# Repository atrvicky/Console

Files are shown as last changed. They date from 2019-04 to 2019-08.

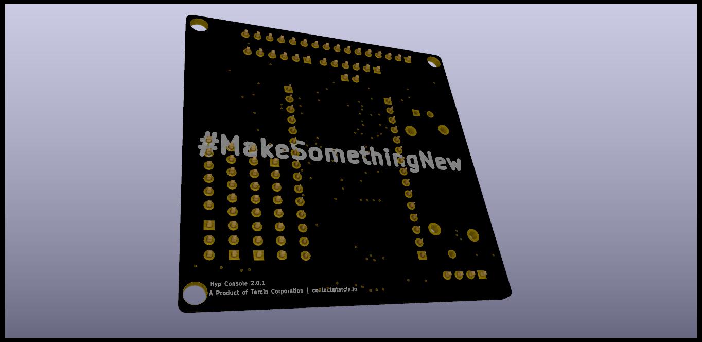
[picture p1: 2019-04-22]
renders/rear.jpg

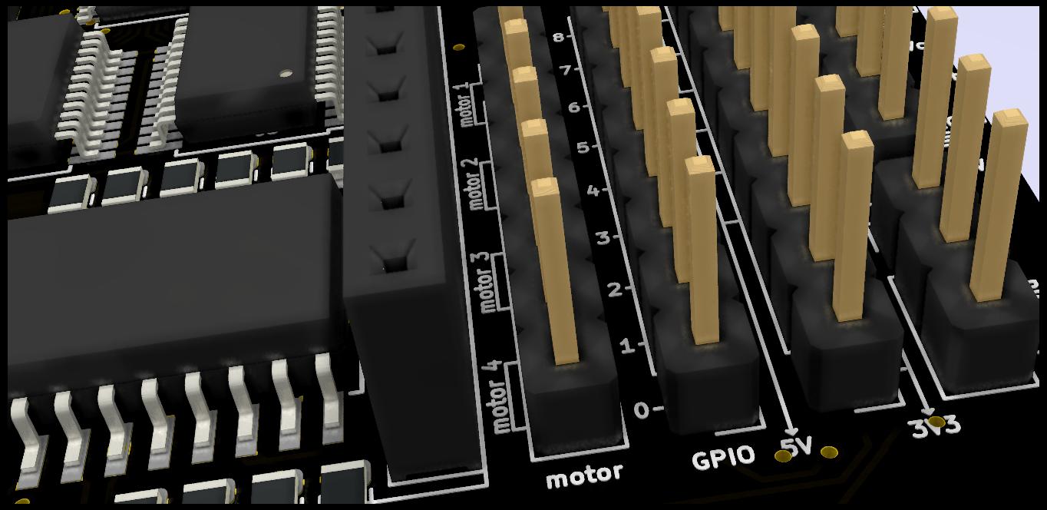
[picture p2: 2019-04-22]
renders/motor_gpio.jpg

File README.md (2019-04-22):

# Console
PCB design of the Hyp Console - an esp8266 powered board, powered by microPython and a ton of embedded functionalities out of the box.

The console has the following features:

* I2C Expander.
* Native LCD support.
* Native support for upto 3 external LEDs (PWM enabled).
* One default LED (PWM enabled).
* Native support for upto 4 DC motors, 2 Steppers, one ultrasound sensor and two infrared sensors.
* Integrated accelerometer with freefall detection, tap detection, doub click detection.
* Dedicated PWM controller and I2C port expander.
* MOSFET controllers for motors for enhanced current delivery to the motors.
* 9 GPIO pins.
* Stabilised 3V3 and 5V outputs.

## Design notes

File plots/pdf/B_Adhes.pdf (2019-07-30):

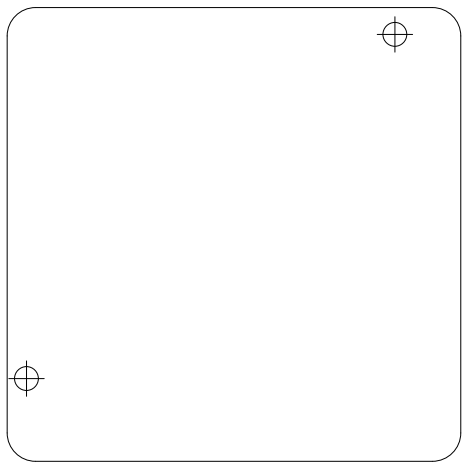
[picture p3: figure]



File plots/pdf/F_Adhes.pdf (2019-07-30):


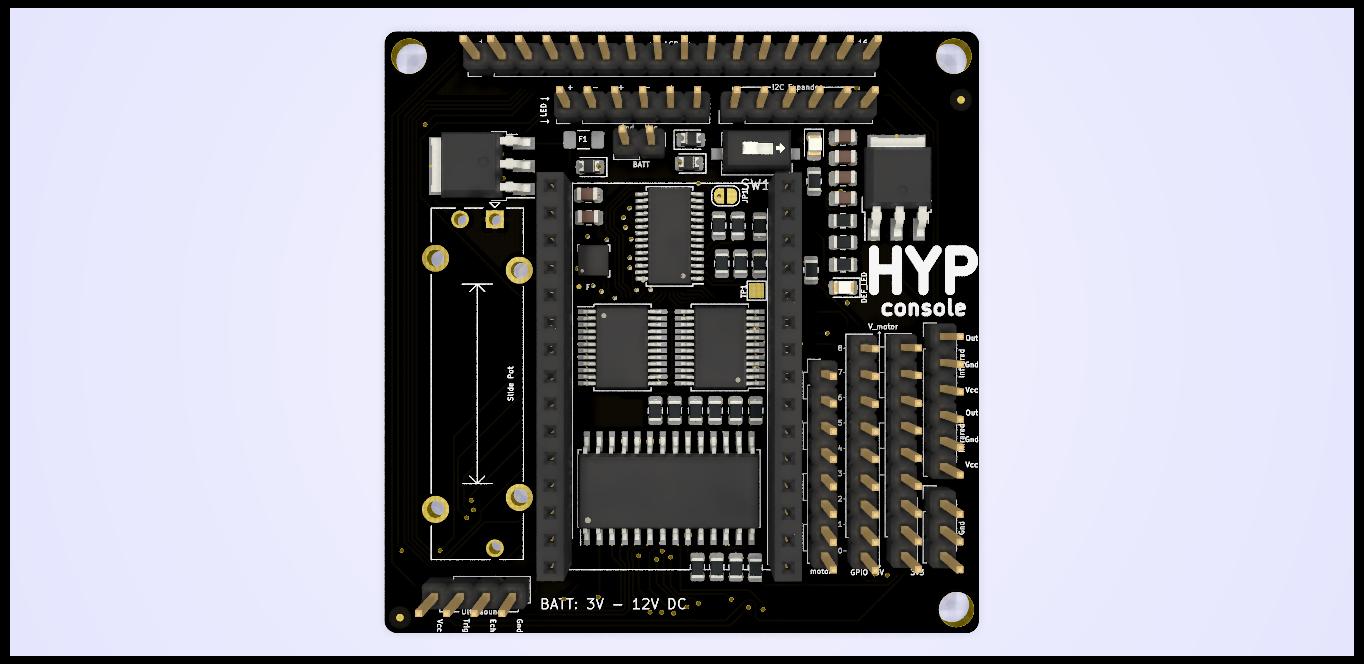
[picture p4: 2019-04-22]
renders/top.jpg

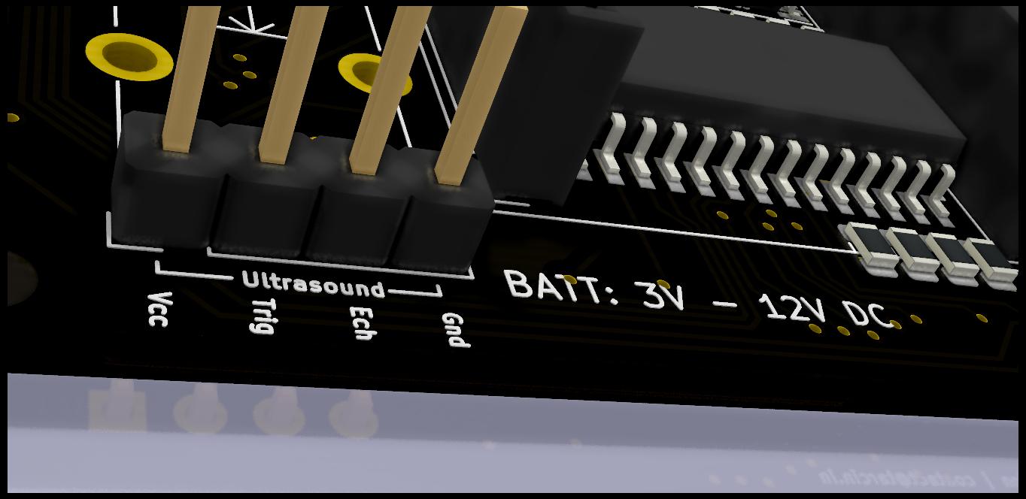
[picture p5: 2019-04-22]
renders/US.jpg

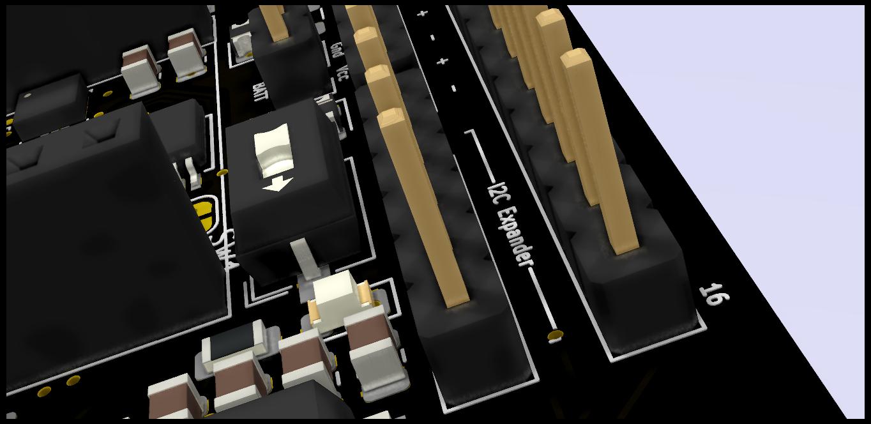
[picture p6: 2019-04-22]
renders/i2c.jpg

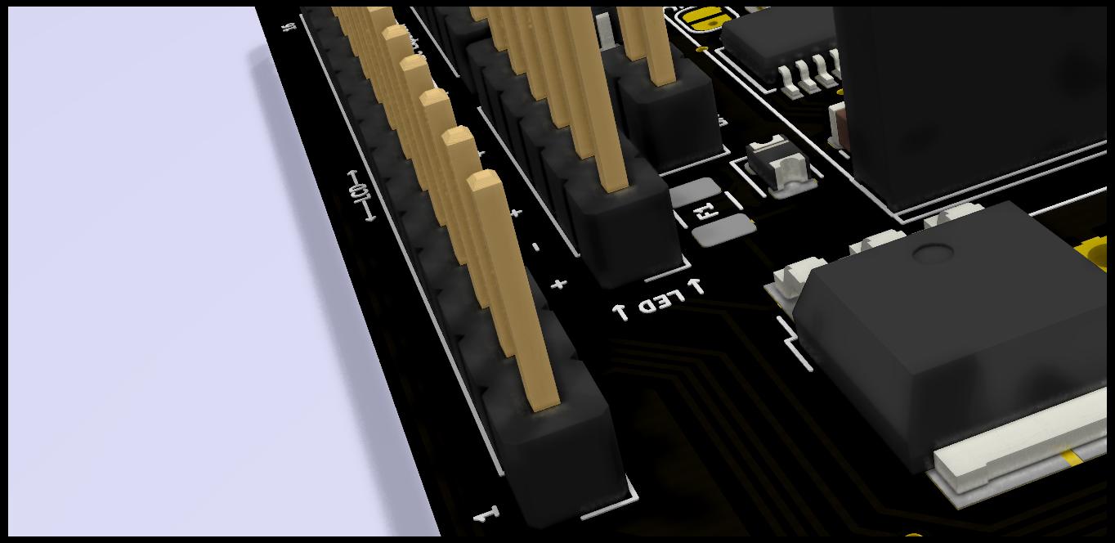
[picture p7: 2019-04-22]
renders/lcd_led.jpg

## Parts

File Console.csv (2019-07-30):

Source: | G:\Studio\Hardware\kiCad\Console\Console.sch
Date: | 07/30/19 22:16:01
Tool: | Eeschema (5.1.0)-1
Generator: | G:\Program Files\KiCad\bin\scripting\plugins/bom_csv_grouped_by_value.py
Component Count: | 56
Individual Components:
Item | Qty | Reference(s) | Value | LibPart | Footprint | Datasheet
 |  | C1 | 10uF | Device:C | Capacitor_SMD:C_0805_2012Metric | ~
 |  | C2 | 1uF | Device:C | Capacitor_SMD:C_0805_2012Metric | ~
 |  | C3 | 1uF | Device:C | Capacitor_SMD:C_0805_2012Metric | ~
 |  | C4 | 1uF | Device:C | Capacitor_SMD:C_0805_2012Metric | ~
 |  | C5 | 10uF | Device:C | Capacitor_SMD:C_0805_2012Metric | ~
 |  | C6 | 1uF | Device:C | Capacitor_SMD:C_0805_2012Metric | ~
 |  | D1 | LED | Device:LED | LED_SMD:LED_0805_2012Metric | ~
 |  | D2 | LED | Device:LED | LED_SMD:LED_0805_2012Metric | ~
 |  | D3 | MBR120 | Device:D | Diode_SMD:D_0805_2012Metric | ~
 |  | D4 | MBR120 | Device:D | Diode_SMD:D_0805_2012Metric | ~
 |  | D5 | MBR120 | Device:D | Diode_SMD:D_0805_2012Metric | ~
 |  | F1 | Fuse | Device:Fuse | Fuse:Fuse_1206_3216Metric | ~
 |  | J1 | batt_in | Connector:Conn_01x02_Male | Connector_PinHeader_2.54mm:PinHeader_1x02_P2.54mm_Vertical | ~
 |  | J2 | 3v3_gnd | Connector:Conn_01x09_Male | Connector_PinHeader_2.54mm:PinHeader_1x09_P2.54mm_Vertical | ~
 |  | J3 | motor_out | Connector:Conn_01x08_Male | Connector_PinHeader_2.54mm:PinHeader_1x08_P2.54mm_Vertical | ~
 |  | J4 | ir_out | Connector:Conn_01x06_Male | Connector_PinHeader_2.54mm:PinHeader_1x06_P2.54mm_Vertical | ~
 |  | J5 | pwr_jumper | Connector:Conn_01x02_Male | Connector_PinHeader_2.54mm:PinHeader_1x02_P2.54mm_Vertical | ~
 |  | J6 | gpio | Connector:Conn_01x09_Male | Connector_PinHeader_2.54mm:PinHeader_1x09_P2.54mm_Vertical | ~
 |  | J7 | led_out | Connector:Conn_01x06_Male | Connector_PinHeader_2.54mm:PinHeader_1x06_P2.54mm_Vertical | ~
 |  | J8 | sensor_in | Connector:Conn_01x04_Male | Connector_PinHeader_2.54mm:PinHeader_1x04_P2.54mm_Vertical | ~
 |  | J9 | i2c_out | Connector:Conn_01x06_Male | Connector_PinHeader_2.54mm:PinHeader_1x06_P2.54mm_Vertical | ~
 |  | J11 | lcd_out | Connector:Conn_01x16_Male | Connector_PinHeader_2.54mm:PinHeader_1x16_P2.54mm_Vertical | ~
 |  | J14 | gnd_out | Connector:Conn_01x03_Male | Connector_PinHeader_2.54mm:PinHeader_1x03_P2.54mm_Vertical | ~
 |  | J17 | node_conn_1 | Connector:Conn_01x15_Female | Connector_PinSocket_2.54mm:PinSocket_1x15_P2.54mm_Vertical | ~
 |  | J18 | node_conn_2 | Connector:Conn_01x15_Female | Connector_PinSocket_2.54mm:PinSocket_1x15_P2.54mm_Vertical | ~
 |  | JP1 | SolderJumper_2_Open | Jumper:SolderJumper_2_Open | Jumper:SolderJumper-2_P1.3mm_Open_RoundedPad1.0x1.5mm | ~
 |  | NMCU1 | nodeMCU | MCU_Espressif:nodeMCU | Custom:NodeMCU
 |  | R1 | 220 | Device:R | Resistor_SMD:R_0805_2012Metric | ~
 |  | R2 | 220 | Device:R | Resistor_SMD:R_0805_2012Metric | ~
 |  | R3 | 10k | Device:R | Resistor_SMD:R_0805_2012Metric | ~
 |  | R4 | 10k | Device:R | Resistor_SMD:R_0805_2012Metric | ~
 |  | R5 | 10k | Device:R | Resistor_SMD:R_0805_2012Metric | ~
 |  | R6 | 10k | Device:R | Resistor_SMD:R_0805_2012Metric | ~
 |  | R7 | 10k | Device:R | Resistor_SMD:R_0805_2012Metric | ~
 |  | R8 | 10k | Device:R | Resistor_SMD:R_0805_2012Metric | ~
 |  | R9 | 10k | Device:R | Resistor_SMD:R_0805_2012Metric | ~
 |  | R10 | 10k | Device:R | Resistor_SMD:R_0805_2012Metric | ~
 |  | R11 | 10k | Device:R | Resistor_SMD:R_0805_2012Metric | ~
 |  | R12 | 10k | Device:R | Resistor_SMD:R_0805_2012Metric | ~
 |  | R13 | 10k | Device:R | Resistor_SMD:R_0805_2012Metric | ~
 |  | R14 | 10k | Device:R | Resistor_SMD:R_0805_2012Metric | ~
 |  | R15 | 10k | Device:R | Resistor_SMD:R_0805_2012Metric | ~
 |  | R16 | 10k | Device:R | Resistor_SMD:R_0805_2012Metric | ~
 |  | R17 | 10k | Device:R | Resistor_SMD:R_0805_2012Metric | ~
 |  | R18 | 10k | Device:R | Resistor_SMD:R_0805_2012Metric | ~
 |  | R19 | 10k | Device:R | Resistor_SMD:R_0805_2012Metric | ~
 |  | R20 | 220 | Device:R | Resistor_SMD:R_0805_2012Metric | ~
 |  | RV1 | R_POT_TRIM | Device:R_POT_TRIM | Potentiometer_THT:Potentiometer_Bourns_PTA2043_Single_Slide | ~
 |  | SW1 | SW_SPDT | Switch:SW_SPDT | Button_Switch_THT:SW_CuK_OS102011MA1QN1_SPDT_Angled | ~
 |  | U1 | AZ1117-3.3 | Regulator_Linear:AZ1117-3.3 | Package_TO_SOT_SMD:TO-252-3_TabPin2 | https://www.diodes.com/assets/Datasheets/AZ1117.pdf
 |  | U2 | LIS3DH | Sensor_Motion:LIS3DH | Package_LGA:LGA-16_3x3mm_P0.5mm_LayoutBorder3x5y | https://www.st.com/resource/en/datasheet/cd00274221.pdf
 |  | U3 | TB6612FNG | Driver_Motor:TB6612FNG | Package_SO:SSOP-24_5.3x8.2mm_P0.65mm | https://toshiba.semicon-storage.com/us/product/linear/motordriver/detail.TB6612FNG.html
 |  | U4 | PCA9685PW | Driver_LED:PCA9685PW | Package_SO:TSSOP-28_4.4x9.7mm_P0.65mm | http://www.nxp.com/documents/data_sheet/PCA9685.pdf
 |  | U5 | TB6612FNG | Driver_Motor:TB6612FNG | Package_SO:SSOP-24_5.3x8.2mm_P0.65mm | https://toshiba.semicon-storage.com/us/product/linear/motordriver/detail.TB6612FNG.html
 |  | U6 | MCP23017_SP | Interface_Expansion:MCP23017_SP | Package_SO:SOIC-28W_7.5x17.9mm_P1.27mm | http://ww1.microchip.com/downloads/en/DeviceDoc/20001952C.pdf
 |  | U7 | AZ1117-5.0 | Regulator_Linear:AZ1117-5.0 | Package_TO_SOT_SMD:TO-252-3_TabPin2 | https://www.diodes.com/assets/Datasheets/AZ1117.pdf
Collated Components:
Item | Qty | Reference(s) | Value | LibPart | Footprint | Datasheet
1 | 2 | C1, C5 | 10uF | Device:C | Capacitor_SMD:C_0805_2012Metric | ~
2 | 4 | C2, C3, C4, C6 | 1uF | Device:C | Capacitor_SMD:C_0805_2012Metric | ~
3 | 2 | D1, D2 | LED | Device:LED | LED_SMD:LED_0805_2012Metric | ~
4 | 3 | D3, D4, D5 | MBR120 | Device:D | Diode_SMD:D_0805_2012Metric | ~
5 | 1 | F1 | Fuse | Device:Fuse | Fuse:Fuse_1206_3216Metric | ~
6 | 1 | J1 | batt_in | Connector:Conn_01x02_Male | Connector_PinHeader_2.54mm:PinHeader_1x02_P2.54mm_Vertical | ~
7 | 1 | J2 | 3v3_gnd | Connector:Conn_01x09_Male | Connector_PinHeader_2.54mm:PinHeader_1x09_P2.54mm_Vertical | ~
8 | 1 | J3 | motor_out | Connector:Conn_01x08_Male | Connector_PinHeader_2.54mm:PinHeader_1x08_P2.54mm_Vertical | ~
9 | 1 | J4 | ir_out | Connector:Conn_01x06_Male | Connector_PinHeader_2.54mm:PinHeader_1x06_P2.54mm_Vertical | ~
10 | 1 | J5 | pwr_jumper | Connector:Conn_01x02_Male | Connector_PinHeader_2.54mm:PinHeader_1x02_P2.54mm_Vertical | ~
11 | 1 | J6 | gpio | Connector:Conn_01x09_Male | Connector_PinHeader_2.54mm:PinHeader_1x09_P2.54mm_Vertical | ~
12 | 1 | J7 | led_out | Connector:Conn_01x06_Male | Connector_PinHeader_2.54mm:PinHeader_1x06_P2.54mm_Vertical | ~
13 | 1 | J8 | sensor_in | Connector:Conn_01x04_Male | Connector_PinHeader_2.54mm:PinHeader_1x04_P2.54mm_Vertical | ~
14 | 1 | J9 | i2c_out | Connector:Conn_01x06_Male | Connector_PinHeader_2.54mm:PinHeader_1x06_P2.54mm_Vertical | ~
15 | 1 | J11 | lcd_out | Connector:Conn_01x16_Male | Connector_PinHeader_2.54mm:PinHeader_1x16_P2.54mm_Vertical | ~
16 | 1 | J14 | gnd_out | Connector:Conn_01x03_Male | Connector_PinHeader_2.54mm:PinHeader_1x03_P2.54mm_Vertical | ~
17 | 1 | J17 | node_conn_1 | Connector:Conn_01x15_Female | Connector_PinSocket_2.54mm:PinSocket_1x15_P2.54mm_Vertical | ~
18 | 1 | J18 | node_conn_2 | Connector:Conn_01x15_Female | Connector_PinSocket_2.54mm:PinSocket_1x15_P2.54mm_Vertical | ~
19 | 1 | JP1 | SolderJumper_2_Open | Jumper:SolderJumper_2_Open | Jumper:SolderJumper-2_P1.3mm_Open_RoundedPad1.0x1.5mm | ~
20 | 1 | NMCU1 | nodeMCU | MCU_Espressif:nodeMCU | Custom:NodeMCU
21 | 3 | R1, R2, R20 | 220 | Device:R | Resistor_SMD:R_0805_2012Metric | ~
22 | 17 | R3, R4, R5, R6, R7, R8, R9, R10, R11, R12, R13, R14, R15, R16, R17, R18, R19 | 10k | Device:R | Resistor_SMD:R_0805_2012Metric | ~
23 | 1 | RV1 | R_POT_TRIM | Device:R_POT_TRIM | Potentiometer_THT:Potentiometer_Bourns_PTA2043_Single_Slide | ~
24 | 1 | SW1 | SW_SPDT | Switch:SW_SPDT | Button_Switch_THT:SW_CuK_OS102011MA1QN1_SPDT_Angled | ~
25 | 1 | U1 | AZ1117-3.3 | Regulator_Linear:AZ1117-3.3 | Package_TO_SOT_SMD:TO-252-3_TabPin2 | https://www.diodes.com/assets/Datasheets/AZ1117.pdf
26 | 1 | U2 | LIS3DH | Sensor_Motion:LIS3DH | Package_LGA:LGA-16_3x3mm_P0.5mm_LayoutBorder3x5y | https://www.st.com/resource/en/datasheet/cd00274221.pdf
27 | 2 | U3, U5 | TB6612FNG | Driver_Motor:TB6612FNG | Package_SO:SSOP-24_5.3x8.2mm_P0.65mm | https://toshiba.semicon-storage.com/us/product/linear/motordriver/detail.TB6612FNG.html
28 | 1 | U4 | PCA9685PW | Driver_LED:PCA9685PW | Package_SO:TSSOP-28_4.4x9.7mm_P0.65mm | http://www.nxp.com/documents/data_sheet/PCA9685.pdf
29 | 1 | U6 | MCP23017_SP | Interface_Expansion:MCP23017_SP | Package_SO:SOIC-28W_7.5x17.9mm_P1.27mm | http://ww1.microchip.com/downloads/en/DeviceDoc/20001952C.pdf
30 | 1 | U7 | AZ1117-5.0 | Regulator_Linear:AZ1117-5.0 | Package_TO_SOT_SMD:TO-252-3_TabPin2 | https://www.diodes.com/assets/Datasheets/AZ1117.pdf

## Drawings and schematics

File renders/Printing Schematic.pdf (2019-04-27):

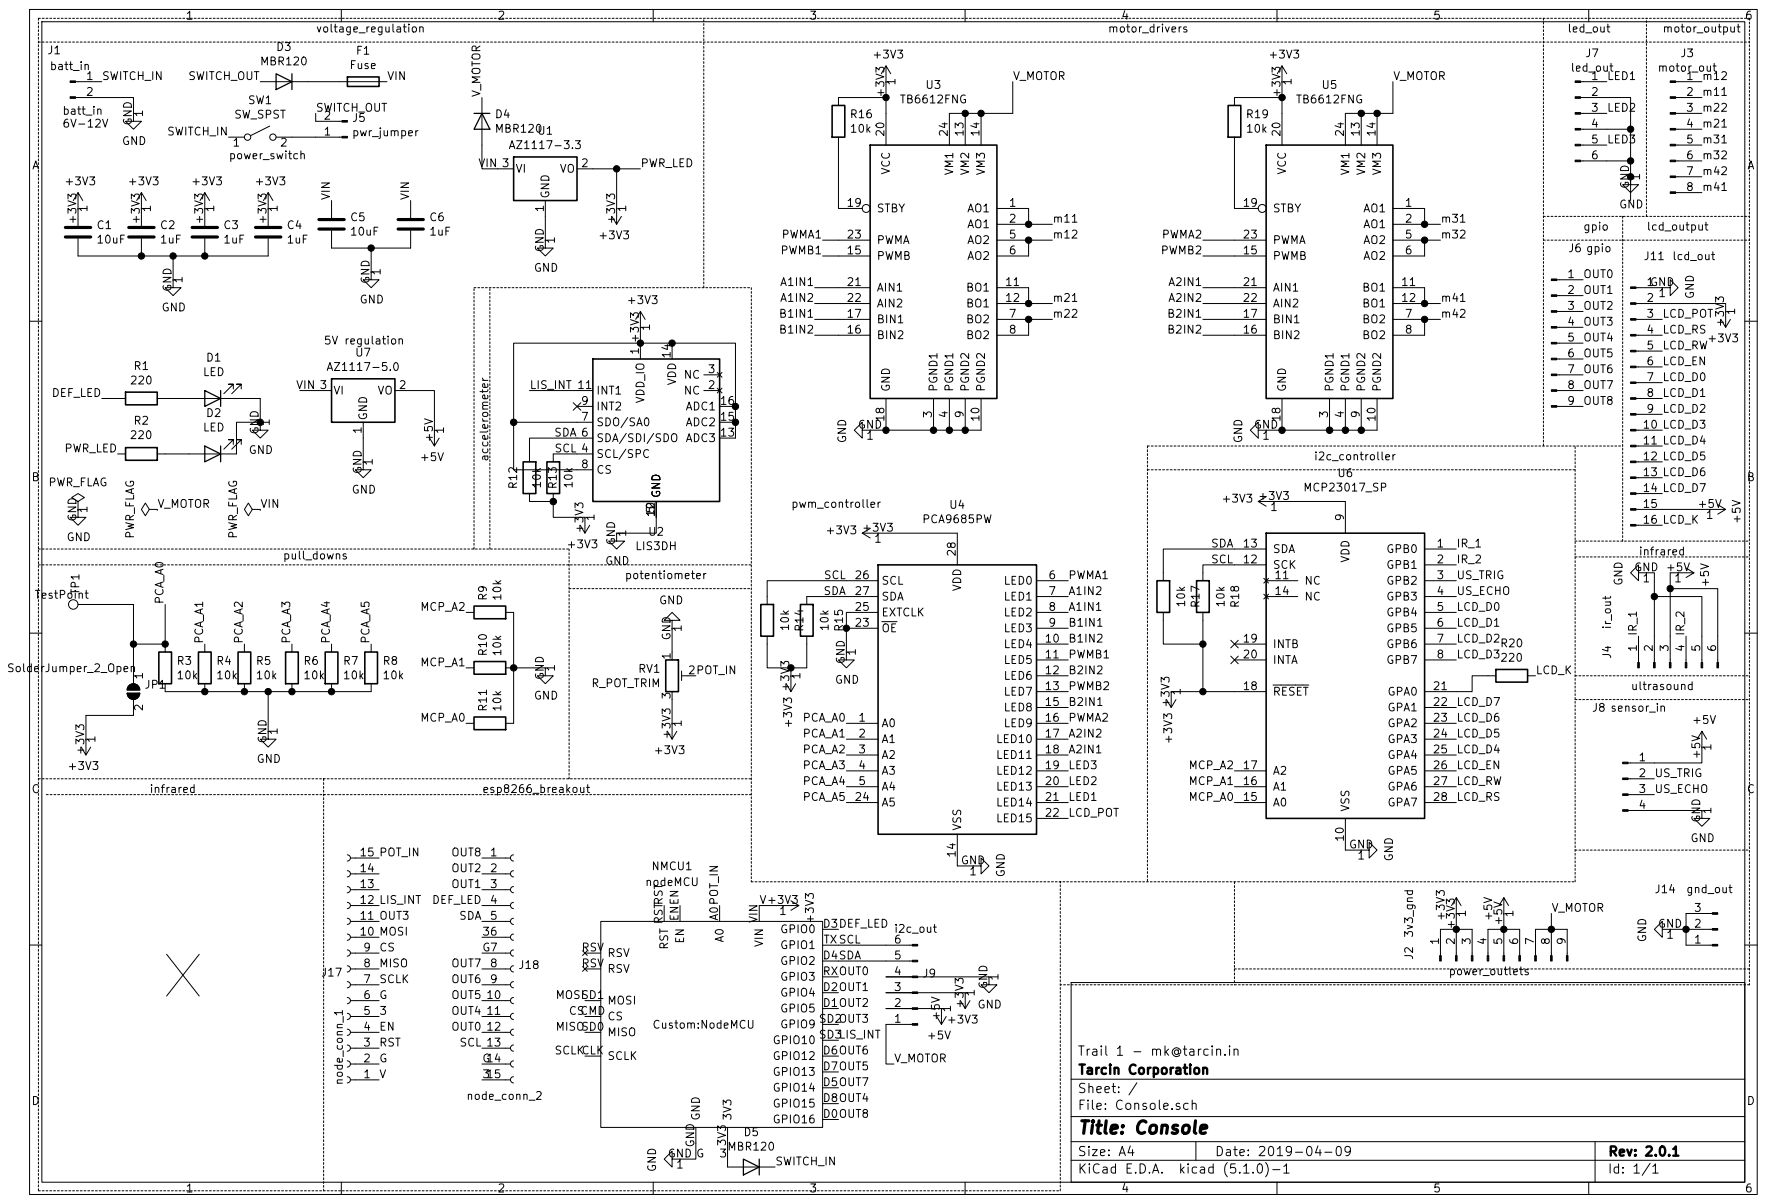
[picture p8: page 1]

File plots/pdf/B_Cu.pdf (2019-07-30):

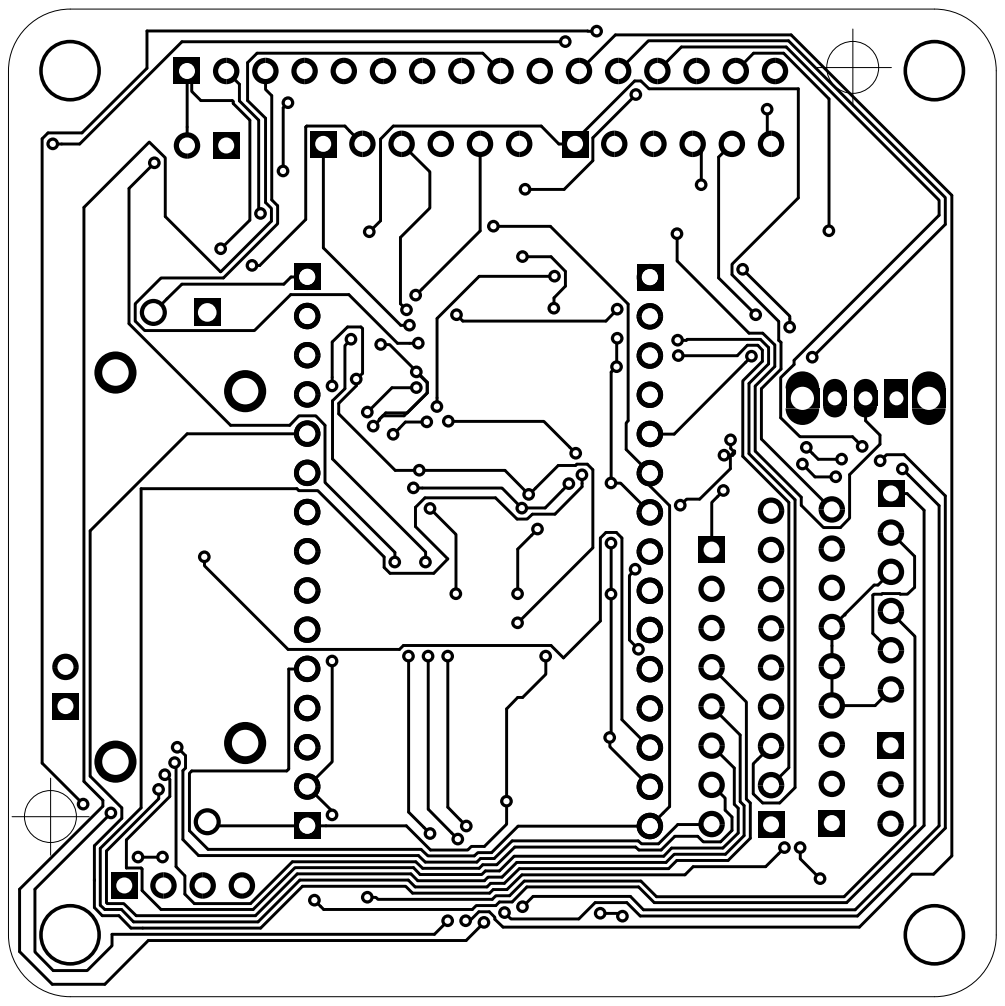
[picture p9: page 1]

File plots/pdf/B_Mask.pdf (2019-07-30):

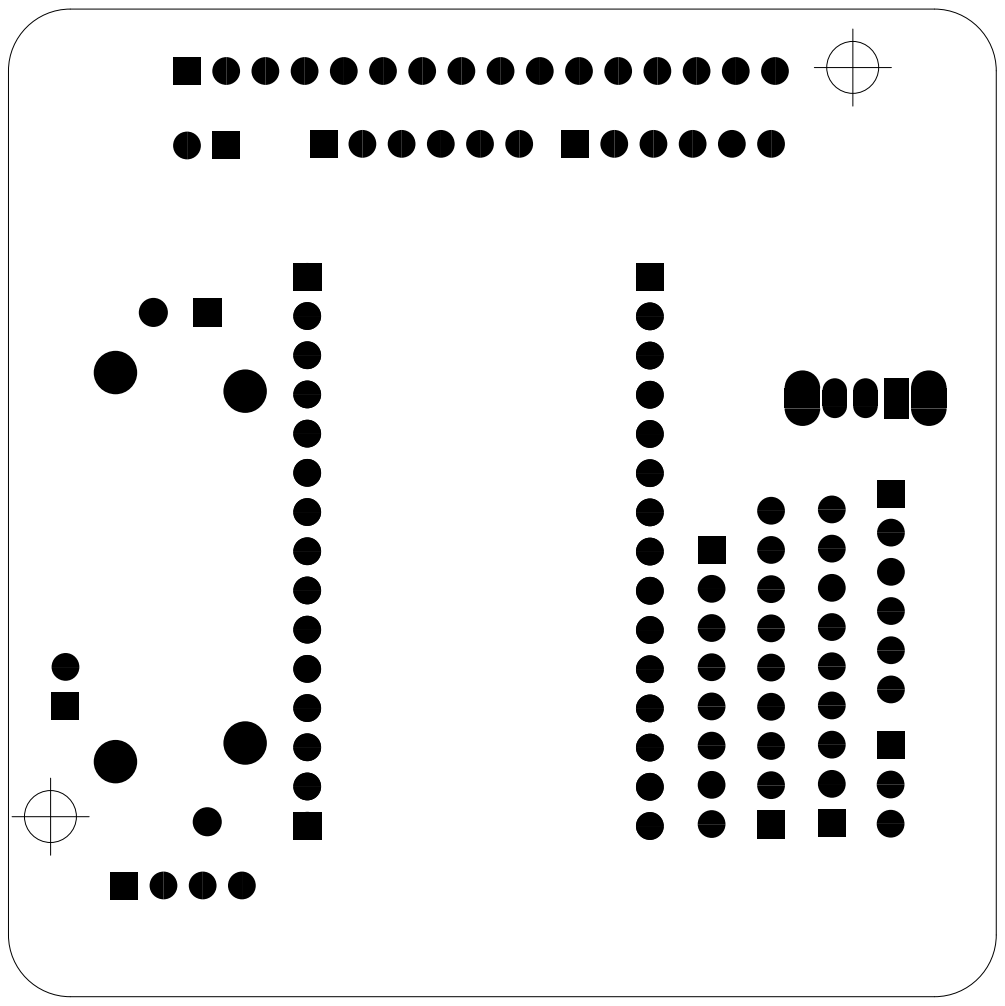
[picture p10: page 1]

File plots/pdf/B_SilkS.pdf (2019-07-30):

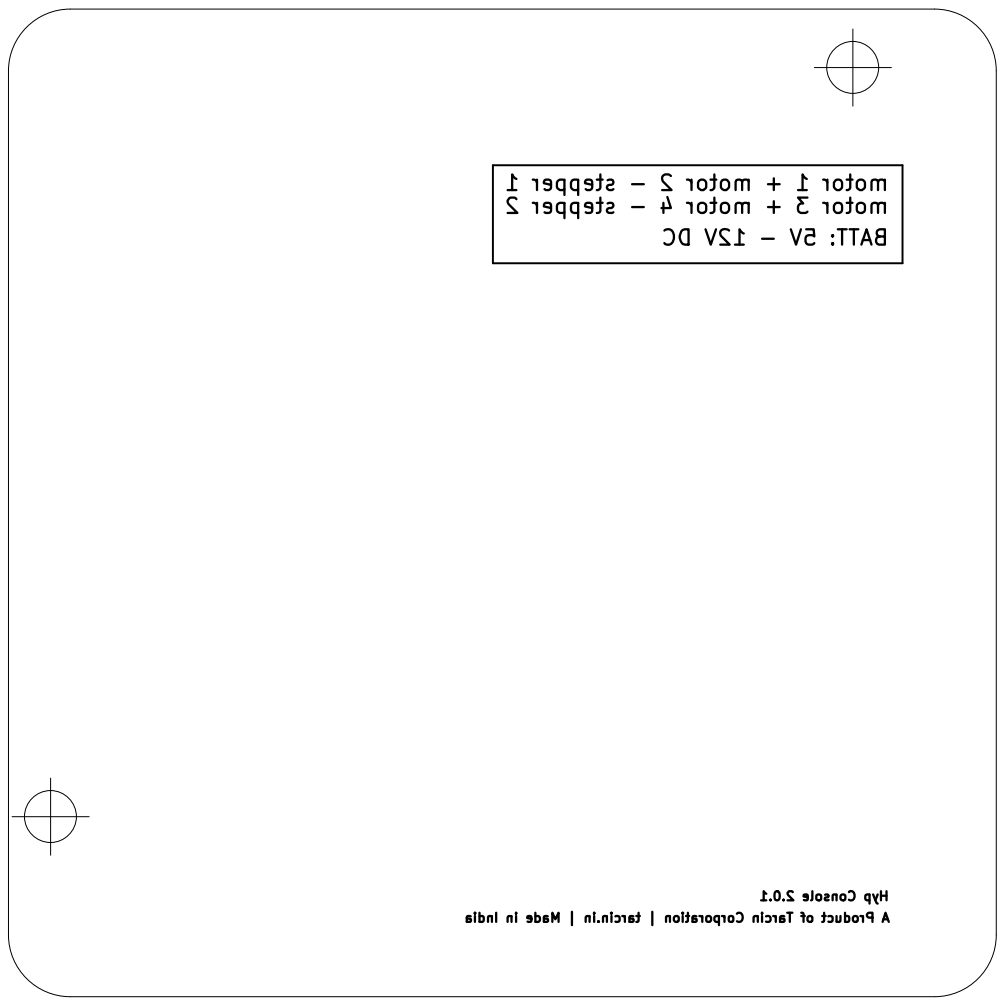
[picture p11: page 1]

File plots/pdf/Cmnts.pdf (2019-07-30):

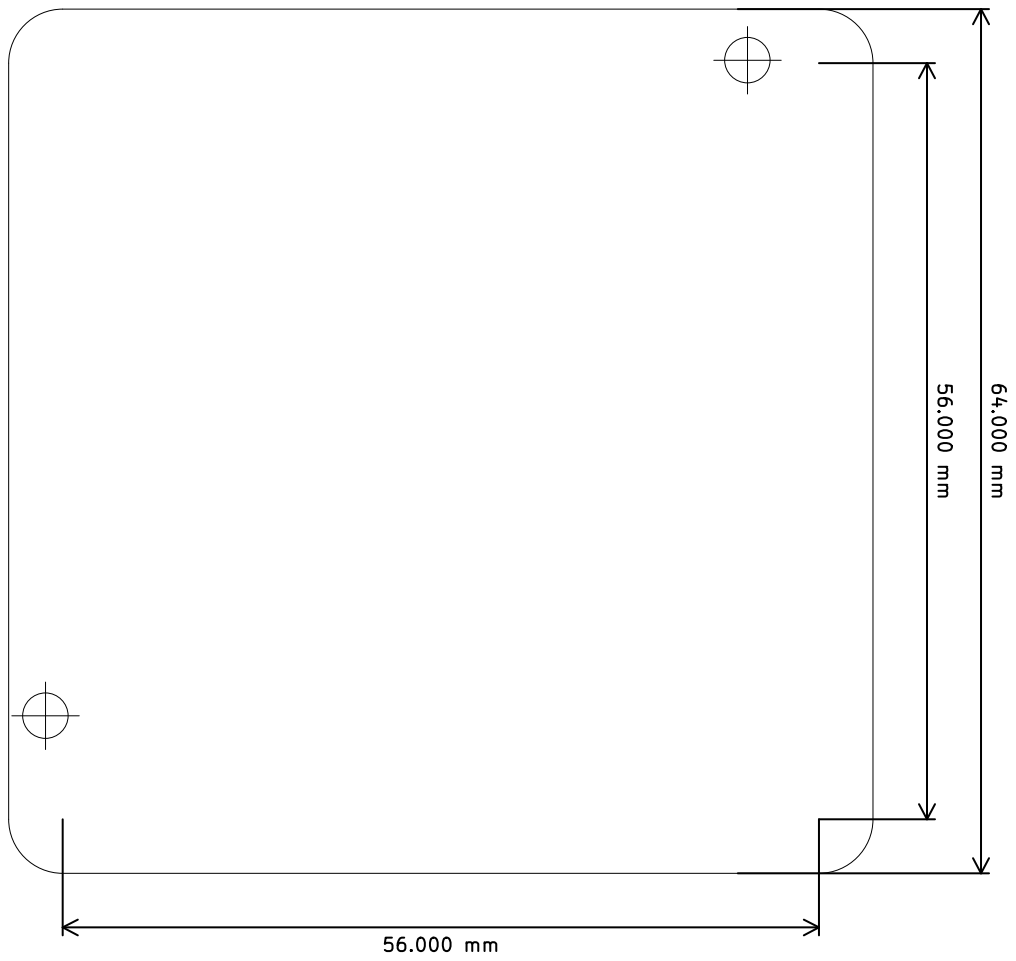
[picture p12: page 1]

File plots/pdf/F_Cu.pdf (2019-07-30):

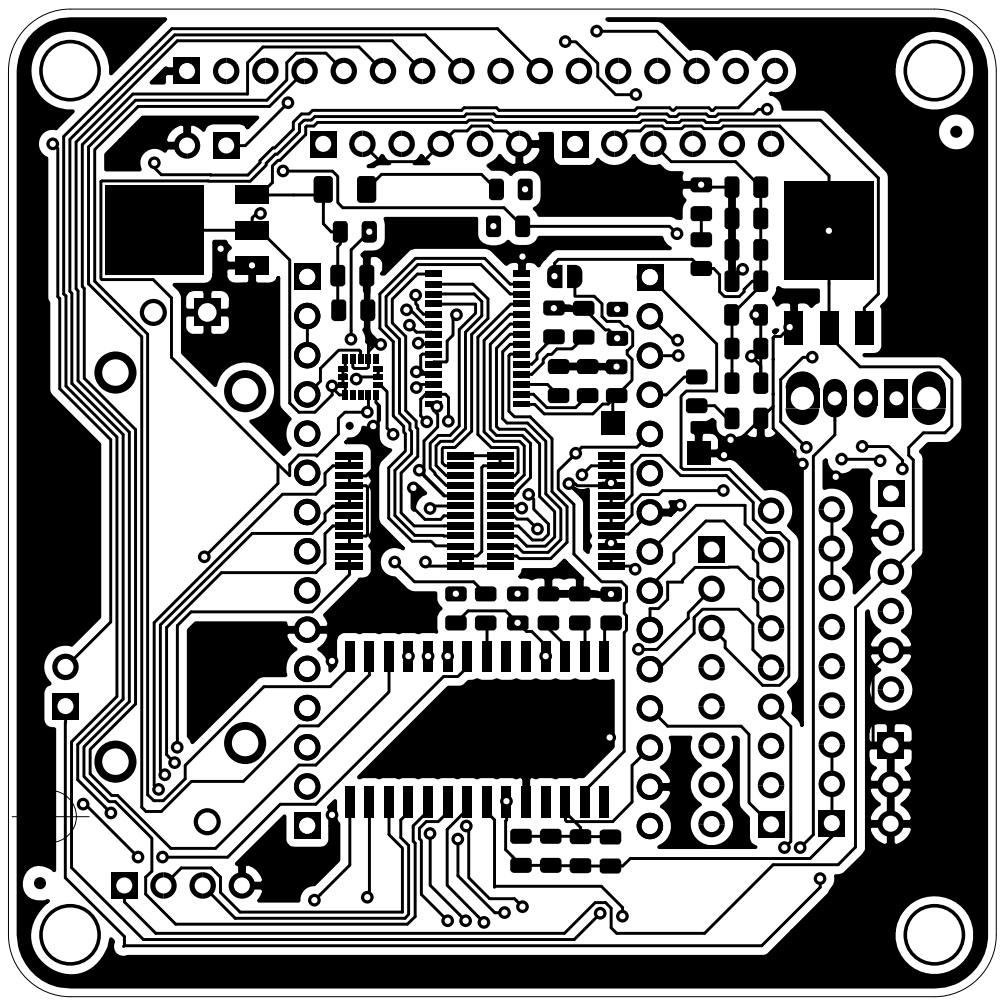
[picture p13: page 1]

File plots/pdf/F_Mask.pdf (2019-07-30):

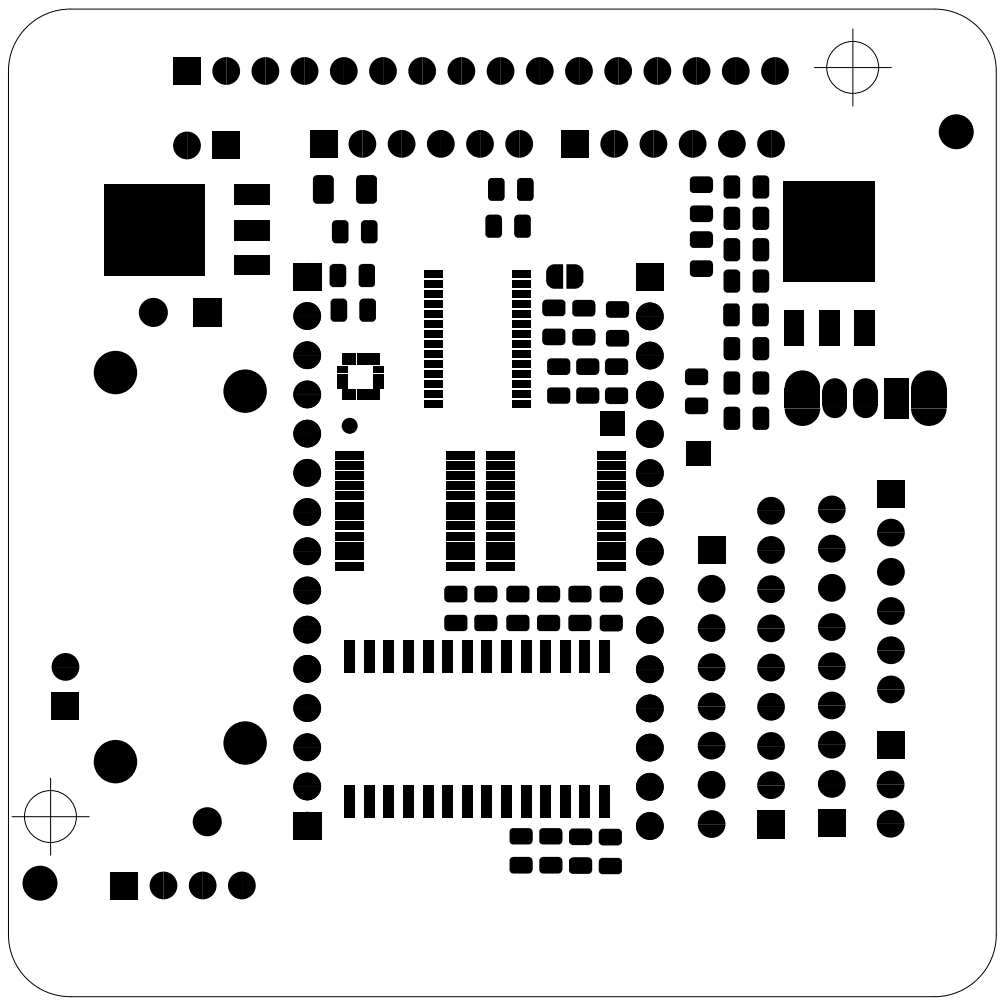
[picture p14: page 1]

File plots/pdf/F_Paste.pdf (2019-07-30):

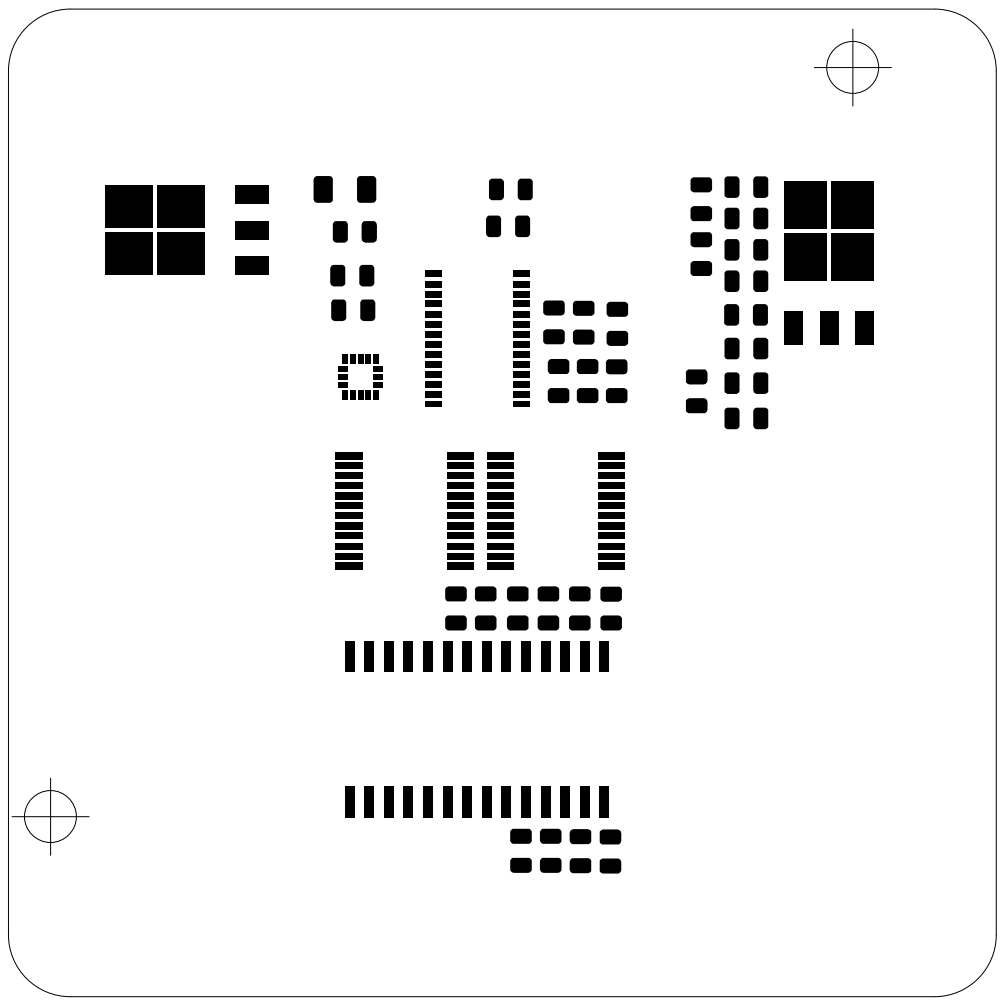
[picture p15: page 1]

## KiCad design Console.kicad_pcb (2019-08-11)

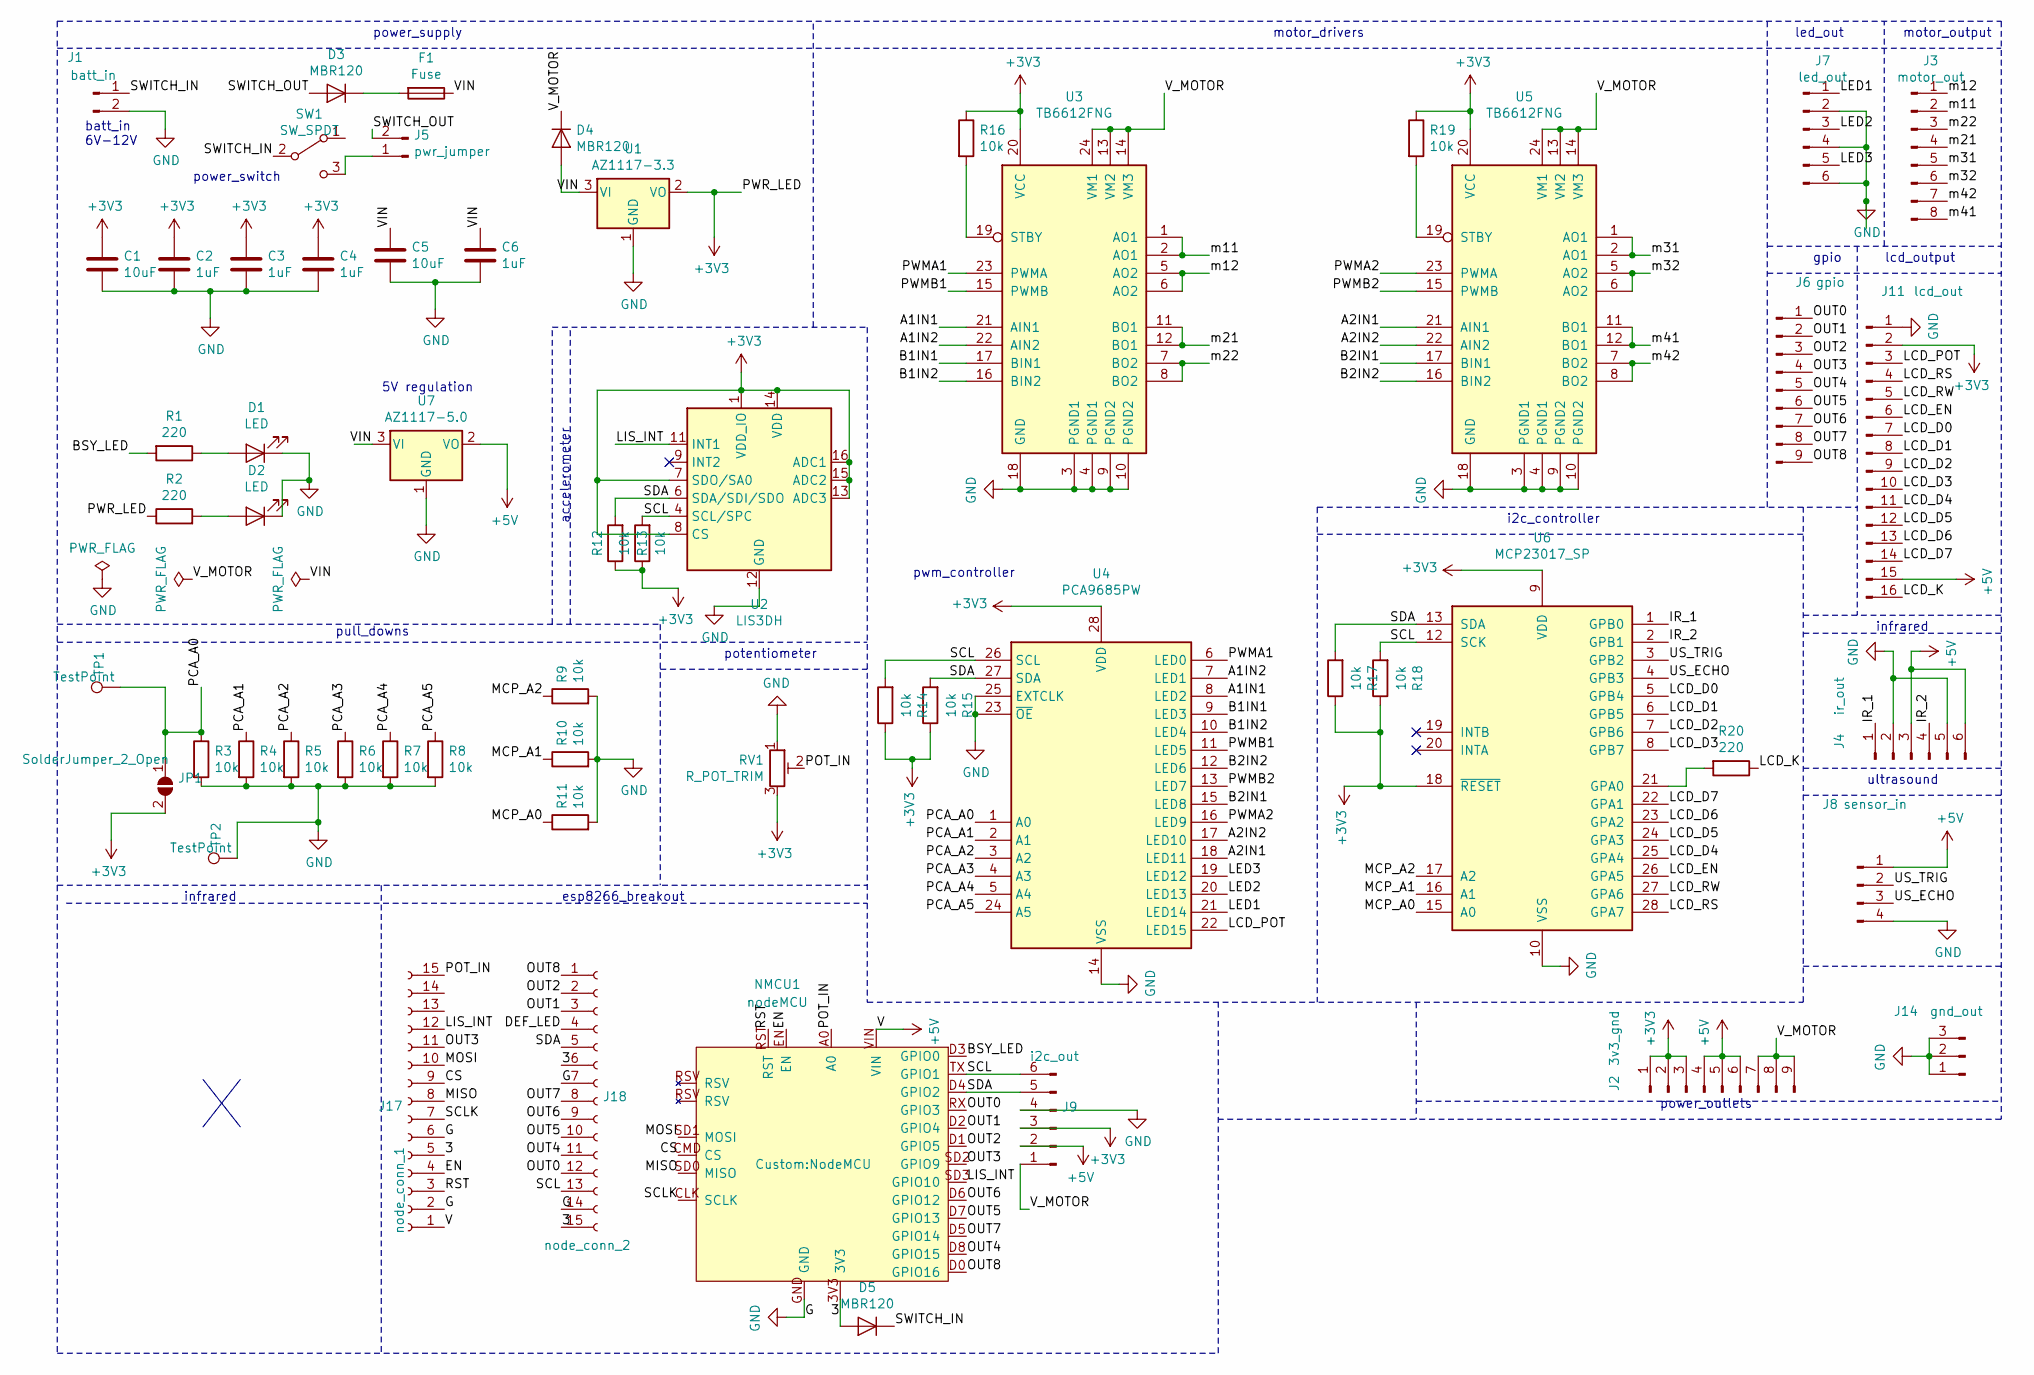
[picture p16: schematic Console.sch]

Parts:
C1, C5: 10uF; C_0805_2012Metric
C2, C3, C4, C6: 1uF; C_0805_2012Metric
D1, D2: LED; LED_0805_2012Metric
D3, D4, D5: MBR120; D_0805_2012Metric
F1: Fuse; Fuse_1206_3216Metric
J1: batt_in; PinHeader_1x02_P2.54mm_Vertical
J2: 3v3_gnd; PinHeader_1x09_P2.54mm_Vertical
J3: motor_out; PinHeader_1x08_P2.54mm_Vertical
J4: ir_out; PinHeader_1x06_P2.54mm_Vertical
J5: pwr_jumper; PinHeader_1x02_P2.54mm_Vertical
J6: gpio; PinHeader_1x09_P2.54mm_Vertical
J7: led_out; PinHeader_1x06_P2.54mm_Vertical
J8: sensor_in; PinHeader_1x04_P2.54mm_Vertical
J9: i2c_out; PinHeader_1x06_P2.54mm_Vertical
J11: lcd_out; PinHeader_1x16_P2.54mm_Vertical
J14: gnd_out; PinHeader_1x03_P2.54mm_Vertical
J17: node_conn_1; PinSocket_1x15_P2.54mm_Vertical
J18: node_conn_2; PinSocket_1x15_P2.54mm_Vertical
JP1: SolderJumper_2_Open; SolderJumper-2_P1.3mm_Open_RoundedPad1.0x1.5mm
NMCU1: nodeMCU; NodeMCU
R1, R2, R20: 220; R_0805_2012Metric
R3, R4, R5, R6, R7, R8, R9, R10, R11, R12, R13, R14, R15, R16, R17, R18, R19: 10k; R_0805_2012Metric
RV1: R_POT_TRIM; Potentiometer_Bourns_PTA2043_Single_Slide
SW1: SW_SPDT; SW_CuK_OS102011MA1QN1_SPDT_Angled
TP1, TP2: TestPoint; TestPoint_Pad_1.5x1.5mm
U1: AZ1117-3.3; TO-252-3_TabPin2
U2: LIS3DH; LGA-16_3x3mm_P0.5mm_LayoutBorder3x5y
U3, U5: TB6612FNG; SSOP-24_5.3x8.2mm_P0.65mm
U4: PCA9685PW; TSSOP-28_4.4x9.7mm_P0.65mm
U6: MCP23017_SP; SOIC-28W_7.5x17.9mm_P1.27mm
U7: AZ1117-5.0; TO-252-3_TabPin2

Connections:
+3V3: C1.1, C2.1, C3.1, C4.1, J2.1, J2.2, J2.3, J9.3, J11.2, JP1.2 (B), R2.1, R12.1, R13.1, R14.1, R15.1, R16.1, R17.1, R18.1, R19.1, RV1.3, U1.2 (VO), U2.1 (VDD_IO), U2.7 (SDO/SA0), U2.8 (CS), U2.13 (ADC3), U2.14 (VDD), U2.15 (ADC2), U2.16 (ADC1), U3.20 (VCC), U4.28 (VDD), U5.20 (VCC), U6.9 (VDD), U6.18 (~RESET~); also elsewhere on the board
+5V: J2.4, J2.5, J2.6, J4.3, J4.6, J8.1, J9.2, J11.15, J17.1, NMCU1.VIN, U7.2 (VO)
/3: D5.2 (A), J17.5, J18.6, J18.15, NMCU1.3V3
/A1IN1: U3.21 (AIN1), U4.8 (LED2)
/A1IN2: U3.22 (AIN2), U4.7 (LED1)
/A2IN1: U4.18 (LED11), U5.21 (AIN1)
/A2IN2: U4.17 (LED10), U5.22 (AIN2)
/B1IN1: U3.17 (BIN1), U4.9 (LED3)
/B1IN2: U3.16 (BIN2), U4.10 (LED4)
/B2IN1: U4.15 (LED8), U5.17 (BIN1)
/B2IN2: U4.12 (LED6), U5.16 (BIN2)
/BSY_LED: NMCU1.D3 (GPIO0), R1.2
/CS: J17.9, NMCU1.CMD (CS)
/DEF_LED: J18.4
/EN: J17.4, NMCU1.EN
/IR_1: J4.1, U6.1 (GPB0)
/IR_2: J4.4, U6.2 (GPB1)
/LCD_D0: J11.7, U6.5 (GPB4)
/LCD_D1: J11.8, U6.6 (GPB5)
/LCD_D2: J11.9, U6.7 (GPB6)
/LCD_D3: J11.10, U6.8 (GPB7)
/LCD_D4: J11.11, U6.25 (GPA4)
/LCD_D5: J11.12, U6.24 (GPA3)
/LCD_D6: J11.13, U6.23 (GPA2)
/LCD_D7: J11.14, U6.22 (GPA1)
/LCD_EN: J11.6, U6.26 (GPA5)
/LCD_K: J11.16, R20.1
/LCD_POT: J11.3, U4.22 (LED15)
/LCD_RS: J11.4, U6.28 (GPA7)
/LCD_RW: J11.5, U6.27 (GPA6)
/LED1: J7.1, U4.21 (LED14)
/LED2: J7.3, U4.20 (LED13)
/LED3: J7.5, U4.19 (LED12)
/LIS_INT: J17.12, NMCU1.SD3 (GPIO10), U2.11 (INT1)
/MCP_A0: R11.1, U6.15 (A0)
/MCP_A1: R10.1, U6.16 (A1)
/MCP_A2: R9.1, U6.17 (A2)
/MISO: J17.8, NMCU1.SD0 (MISO)
/MOSI: J17.10, NMCU1.SD1 (MOSI)
/OUT0: J6.1, J18.12, NMCU1.RX (GPIO3)
/OUT1: J6.2, J18.3, NMCU1.D2 (GPIO4)
/OUT2: J6.3, J18.2, NMCU1.D1 (GPIO5)
/OUT3: J6.4, J17.11, NMCU1.SD2 (GPIO9)
/OUT4: J6.5, J18.11, NMCU1.D8 (GPIO15)
/OUT5: J6.6, J18.10, NMCU1.D7 (GPIO13)
/OUT6: J6.7, J18.9, NMCU1.D6 (GPIO12)
/OUT7: J6.8, J18.8, NMCU1.D5 (GPIO14)
/OUT8: J6.9, J18.1, NMCU1.D0 (GPIO16)
/PCA_A0: JP1.1 (A), R3.1, TP1.1, U4.1 (A0)
/PCA_A1: R4.1, U4.2 (A1)
/PCA_A2: R5.1, U4.3 (A2)
/PCA_A3: R6.1, U4.4 (A3)
/PCA_A4: R7.1, U4.5 (A4)
/PCA_A5: R8.1, U4.24 (A5)
/POT_IN: J17.15, NMCU1.A0, RV1.2
/PWMA1: U3.23 (PWMA), U4.6 (LED0)
/PWMA2: U4.16 (LED9), U5.23 (PWMA)
/PWMB1: U3.15 (PWMB), U4.11 (LED5)
/PWMB2: U4.13 (LED7), U5.15 (PWMB)
/RST: J17.3, NMCU1.RST
/SCLK: J17.7, NMCU1.CLK (SCLK)
/SDA: J9.5, J18.5, NMCU1.D4 (GPIO2), R12.2, R15.2, R17.2, U2.6 (SDA/SDI/SDO), U4.27 (SDA), U6.13 (SDA)
/SWITCH_IN: D5.1 (K), J1.1, SW1.2 (B)
/SWITCH_OUT: D3.2 (A), J5.2
/US_ECHO: J8.3, U6.4 (GPB3)
/US_TRIG: J8.2, U6.3 (GPB2)
/VIN: C5.1, C6.1, D4.2 (A), F1.1, U1.3 (VI), U7.3 (VI); also elsewhere on the board
/V_MOTOR: D4.1 (K), J2.7, J2.8, J2.9, J9.1, U3.13 (VM2), U3.14 (VM3), U3.24 (VM1), U5.13 (VM2), U5.14 (VM3), U5.24 (VM1)
/m11: J3.2, U3.1 (AO1), U3.2 (AO1)
/m12: J3.1, U3.5 (AO2), U3.6 (AO2)
/m21: J3.4, U3.11 (BO1), U3.12 (BO1)
/m22: J3.3, U3.7 (BO2), U3.8 (BO2)
/m31: J3.5, U5.1 (AO1), U5.2 (AO1)
/m32: J3.6, U5.5 (AO2), U5.6 (AO2)
/m41: J3.8, U5.11 (BO1), U5.12 (BO1)
/m42: J3.7, U5.7 (BO2), U5.8 (BO2)
GND: C1.2, C2.2, C3.2, C4.2, C5.2, C6.2, D1.1 (K), D2.1 (K), J1.2, J4.2, J4.5, J7.2, J7.4, J7.6, J8.4, J9.4, J11.1, J14.1, J14.2, J14.3, J17.2, J17.6, J18.7, J18.14, NMCU1.GND, R3.2, R4.2, R5.2, R6.2, R7.2, R8.2, R9.2, R10.2, R11.2, RV1.1, TP2.1, U1.1 (GND), U2.5 (GND), U2.10 (GND), U2.12 (GND), U3.3 (PGND1), U3.4 (PGND1), U3.9 (PGND2), U3.10 (PGND2), U3.18 (GND), U4.14 (VSS), U4.23 (~OE), U4.25 (EXTCLK), U5.3 (PGND1), U5.4 (PGND1), U5.9 (PGND2), U5.10 (PGND2), U5.18 (GND), U6.10 (VSS), U7.1 (GND)
unnamed: D1.2 (A), R1.1
unnamed: D2.2 (A), R2.2
unnamed 79: D3.1 (K), F1.2; also elsewhere on the board
unnamed: J5.1, SW1.3 (C)
unnamed: R19.2, U5.19 (STBY)
unnamed: R20.2, U6.21 (GPA0)

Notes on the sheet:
batt_in 6V-12V
power_switch
pull_downs
power_supply
accelerometer
motor_drivers
pwm_controller
potentiometer
i2c_controller
esp8266_breakout
led_out
gpio
ultrasound
lcd_output
infrared
5V regulation
infrared
power_outlets
motor_output

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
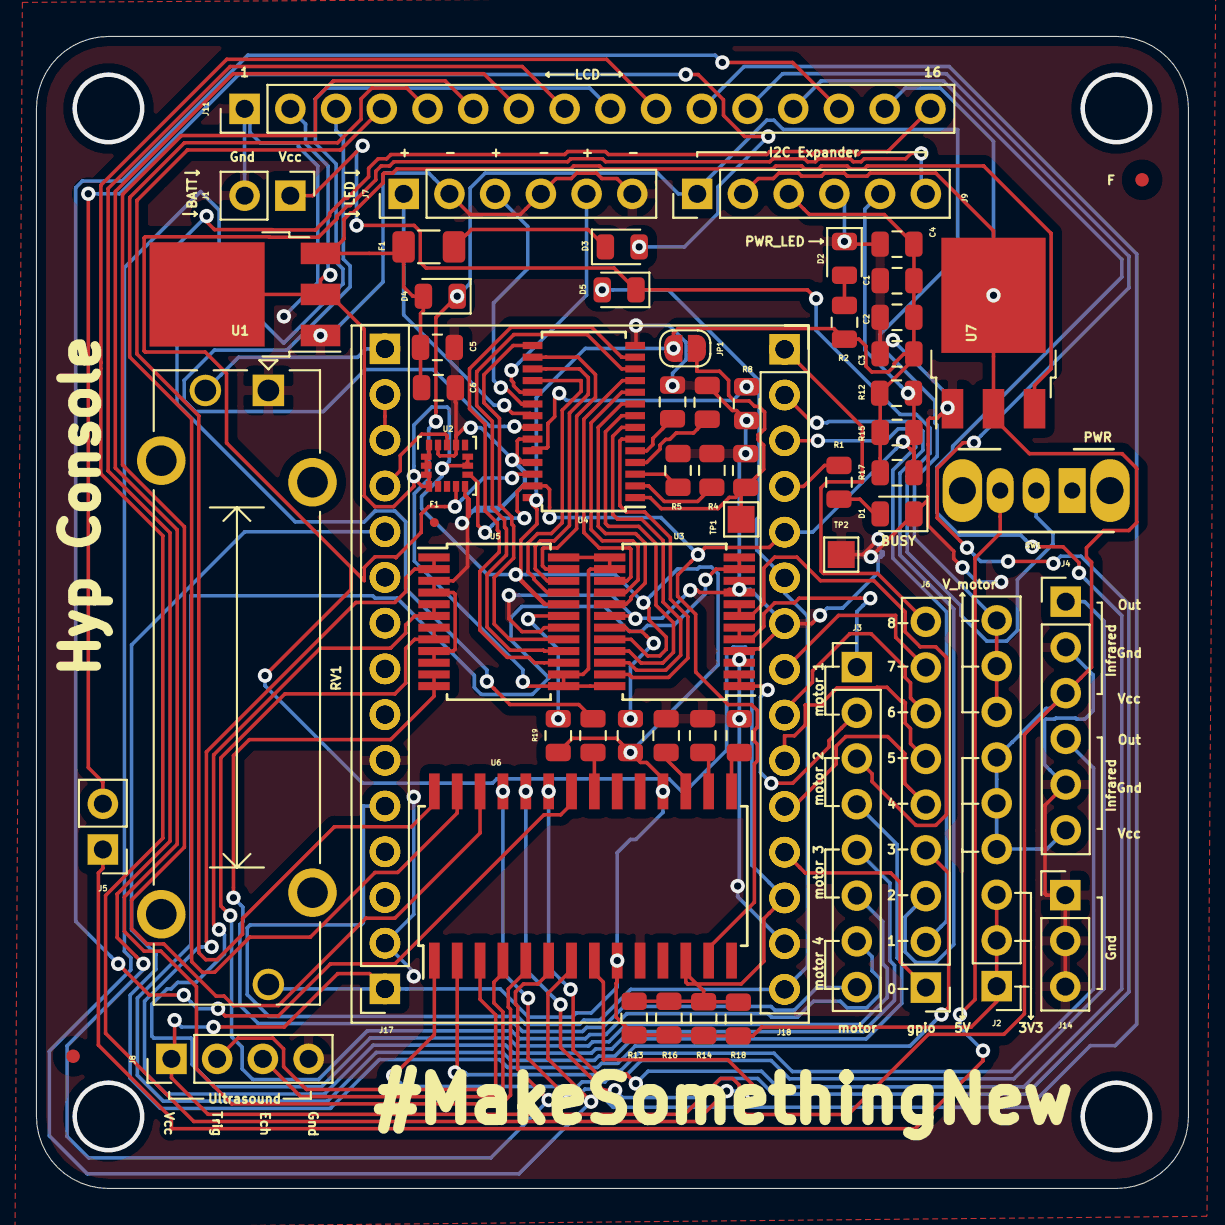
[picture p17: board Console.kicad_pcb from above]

Board: 2 copper layers, 64.0 x 64.0 mm, 62 parts (0 on the bottom side), 84 nets.

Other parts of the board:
F: Fiducial_0.75mm_Mask2.25mm
F1#2: Fuse; Fuse_1206_3216Metric
F#2: Fiducial_0.75mm_Mask2.25mm
R16#2: 10k; R_0805_2012Metric

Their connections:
+3V3: R16#2.1; also elsewhere on the board
/VIN: F1#2.1; also elsewhere on the board
unnamed 79: F1#2.2; also elsewhere on the board

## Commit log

2019-04-22 Design 2.0.1 finalised
    Added the following functionalities
    * I2C Expander.
    * Native LCD support.
    * Native support for upto 3 external LEDs (PWM enabled).
    * One default LED (PWM enabled).
    * Native support for upto 4 DC motors, 2 Steppers, one ultrasound sensor and two infrared sensors.
    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
    [Console.sch]
2019-04-27 Add Busy LED
    Changed the DEF_LED to BSY_LED to indicate network business. The default led in the breakout board remains the same.
    [Console.kicad_pcb, Console.sch]
2019-04-28 Generated gerbers
    [Console-B_Cu.gbr, Console-B_Mask.gbr, Console-B_Paste.gbr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]
2019-05-16 Updated for production
    Changed the pad and silkScreen overlap in some places
    [BOM Console.xlsx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]
2019-05-20 Changed Switch footprint
    Changed the switch to SPDT and its footprint to a mouser available switch and made all the legends visible. Added a testpoint for gnd. Final Check yet to be done
    [BOM Console.xlsx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]
2019-05-20 Design approved for production
    [Console.sch]
2019-05-21 removed residue after modifying the switch
    [Console-B_Cu.gbr, Console-B_Mask.gbr, Console-B_Paste.gbr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]
2019-05-22 Updated the board size
    Using a pitch of 8mm,the drills were adjusted and the board size was standardized to 64x64
    [Console-B_Cu.gbr, Console-B_Mask.gbr, Console-B_Paste.gbr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]
2019-07-30 About production
    [Console.csv, Console.kicad_pcb]
2019-08-11 Change NodeMCU Vin
    Update the nodeMcu supply voltage to 5v from 3v3
    [Console.kicad_pcb, Console.sch]
